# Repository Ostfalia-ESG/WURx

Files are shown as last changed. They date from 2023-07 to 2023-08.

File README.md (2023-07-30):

# Wake-up Receiver (WURx)
This project includes the main PCB design as well as the software for a semi-active Wake-up Receiver with addressing capabilities.

The WURx is the green part of the overall architecture shown in the following figure.
More details are found in the associated publications ([HotWire], [STFO]).

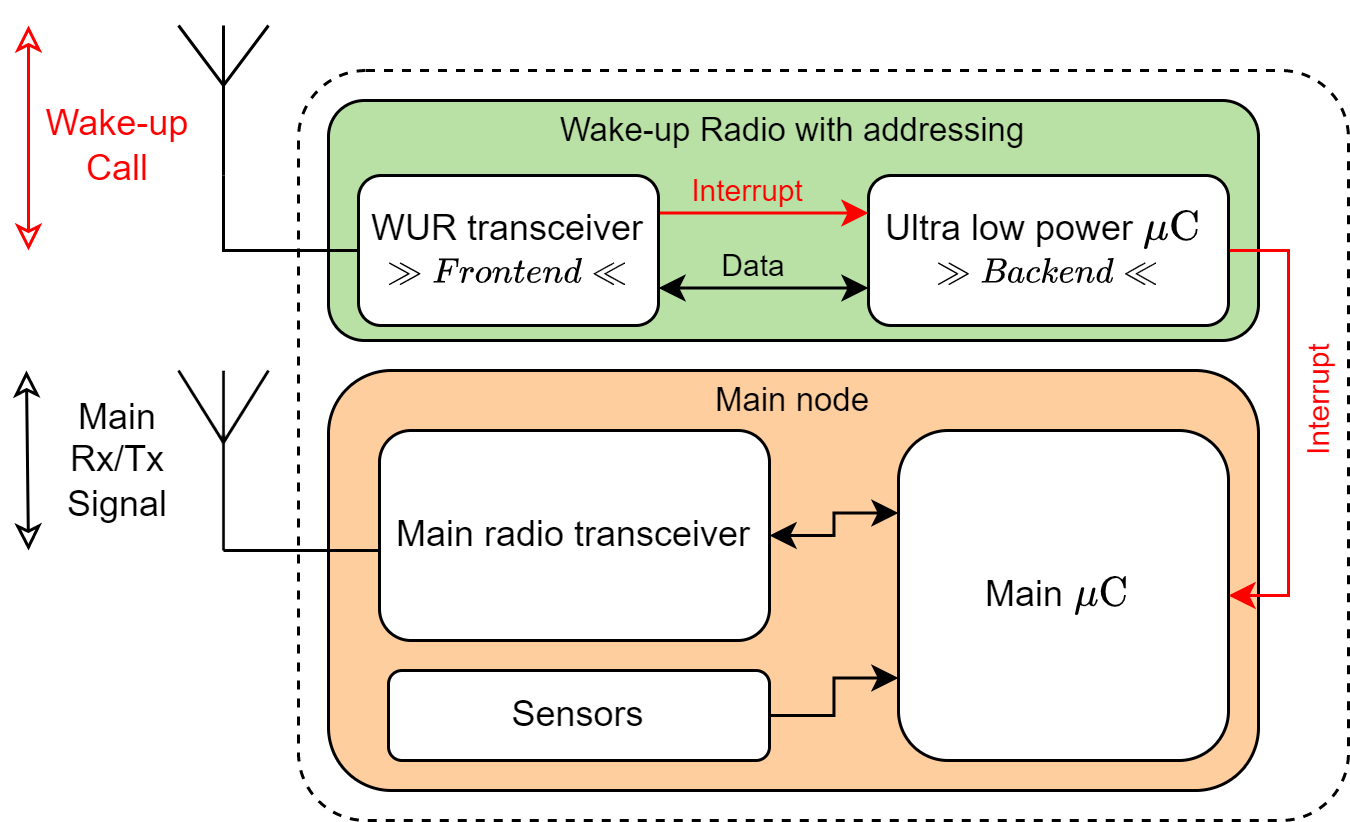
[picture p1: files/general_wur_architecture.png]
overall wur architecture


## Features
This implementation is an experimental solution for research purposes and has the following functions:

- Different comparators in the frontend are possible (TLV3691, LPV7215, TS881)
- Configurable address
- Configurable address length (0 to 32 bit)
- Configurable bitrate (100 to 25.6 kbps, with automatic clock adjustment)
- Backend supports deep-sleep and Switch (by) Transistors Fully Off (STFO) mode (see [STFO])

## Requirements
- Hardware
  - The PCBs (frontend and backend) designed in KiCad (see folder pcb/)
  - A transmitter (e.g. a Software Defined Radio like the USRP B210 with GNU Radio) is needed to send a Wake-up Call
- To program the $\mu C$ (a PIC16LF1823)
    - [MPLAB&reg; X IDE](https://www.microchip.com/en-us/tools-resources/develop/mplab-x-ide#)
    - [MPLAB&reg; XC8 C-Compiler](https://www.microchip.com/en-us/tools-resources/develop/mplab-xc-compilers/downloads-documentation#XC8)

## UART interface
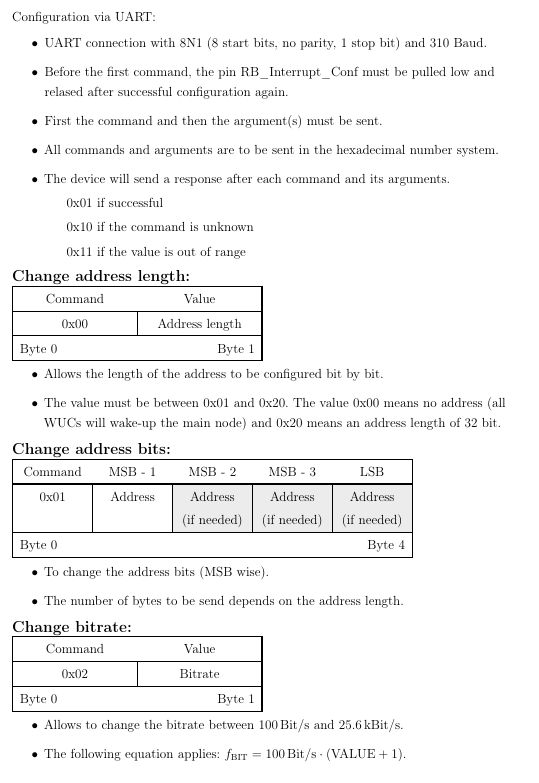
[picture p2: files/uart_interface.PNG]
UART Interface


[HotWire]: https://paper1
[STFO]: https://paper2

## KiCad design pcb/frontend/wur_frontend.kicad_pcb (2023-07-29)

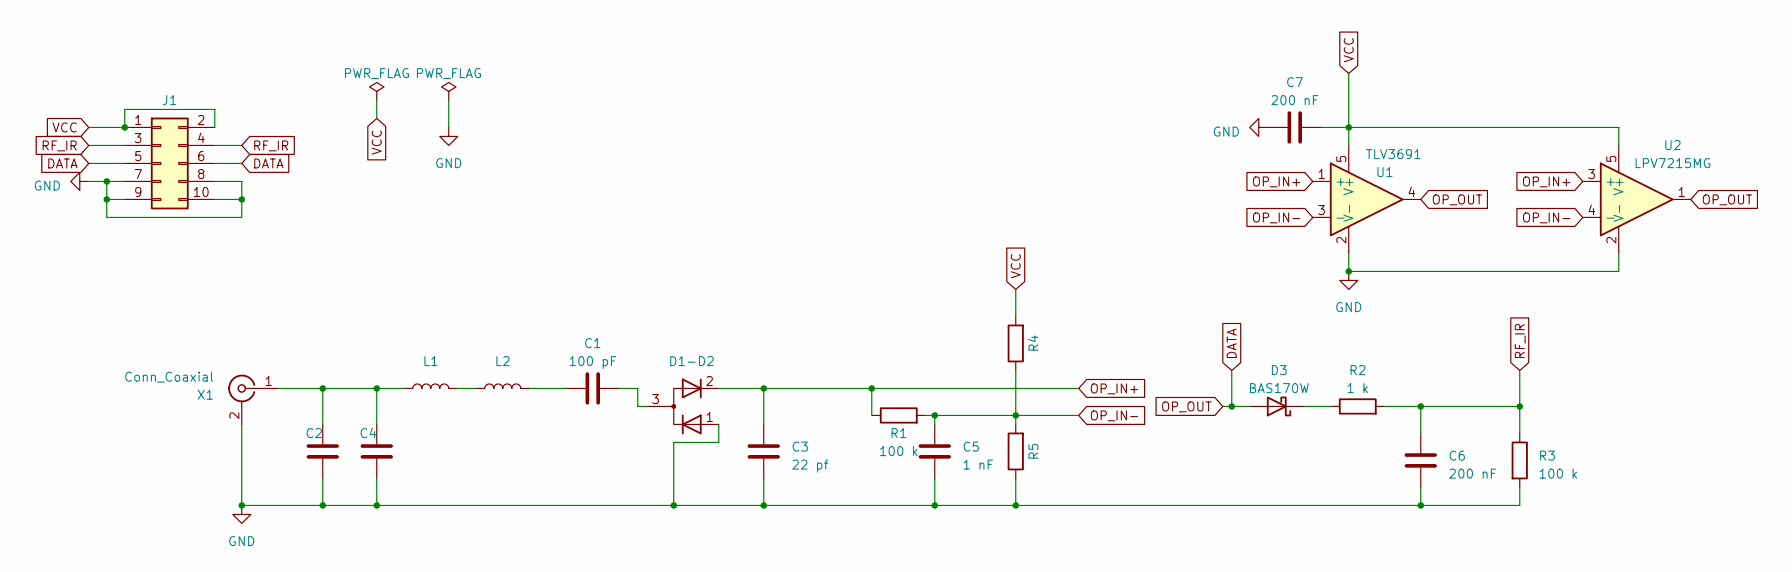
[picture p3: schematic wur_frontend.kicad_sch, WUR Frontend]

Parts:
C1: 100 pF; C_0603_1608Metric_Pad1.08x0.95mm_HandSolder
C2, C4: C_0603_1608Metric_Pad1.08x0.95mm_HandSolder
C3: 22 pf; C_0603_1608Metric_Pad1.08x0.95mm_HandSolder
C5: 1 nF; C_0603_1608Metric_Pad1.08x0.95mm_HandSolder
C6, C7: 200 nF; C_0603_1608Metric_Pad1.08x0.95mm_HandSolder
D1-D2: SOT-23
D3: BAS170W; D_SOD-323_HandSoldering
J1: Conn_02x05_Odd_Even; PinHeader_2x05_P2.54mm_Vertical
L1, L2: L; L_0603_1608Metric_Pad1.05x0.95mm_HandSolder
R1, R3: 100 k; R_0603_1608Metric_Pad0.98x0.95mm_HandSolder
R2: 1 k; R_0603_1608Metric_Pad0.98x0.95mm_HandSolder
R4, R5: R_0603_1608Metric_Pad0.98x0.95mm_HandSolder
U1: TLV3691; DCK_SC70
U2: LPV7215MG; DCK_SC70
X1: Conn_Coaxial; SMA_Amphenol_132289_EdgeMount

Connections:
DATA: D3.2 (A), J1.5, J1.6, U1.4, U2.1
GND: C2.2, C3.1, C4.2, C5.1, C6.1, C7.1, D1-D2.1 (K), J1.7, J1.8, J1.9, J1.10, R3.2, R5.1, U1.2 (V-), U2.2 (V-), X1.2 (Ext)
unnamed: C1.1, L2.2
unnamed: C1.2, D1-D2.3 (A)
unnamed: D3.1 (K), R2.1
unnamed: L1.2, L2.1
unnamed: C2.1, C4.1, L1.1, X1.1 (In)
OP_IN+: C3.2, D1-D2.2 (K), R1.1, U1.1 (+), U2.3 (+)
OP_IN-: C5.2, R1.2, R4.1, R5.2, U1.3 (-), U2.4 (-)
RF_IR: C6.2, J1.3, J1.4, R2.2, R3.1
VCC: C7.2, J1.1, J1.2, R4.2, U1.5 (V+), U2.5 (V+)

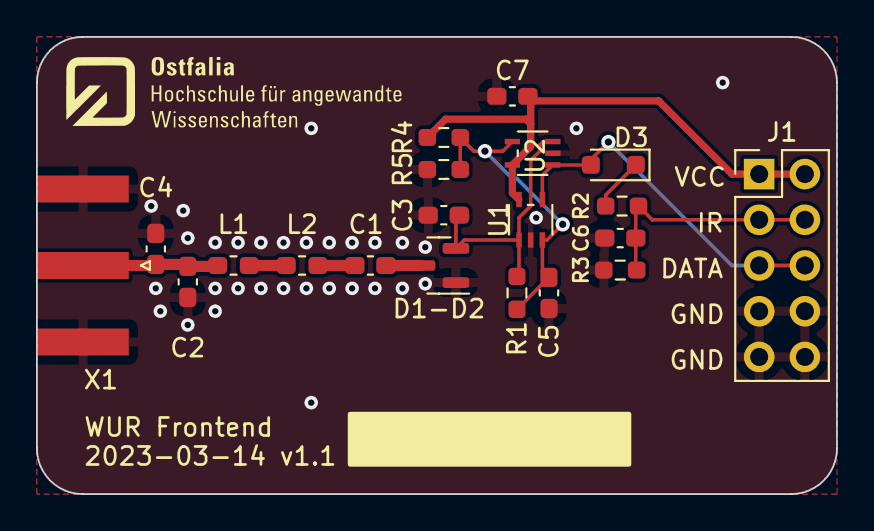
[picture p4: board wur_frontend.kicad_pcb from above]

Board: 2 copper layers, 44.5 x 25.4 mm, 20 parts (0 on the bottom side), 11 nets.

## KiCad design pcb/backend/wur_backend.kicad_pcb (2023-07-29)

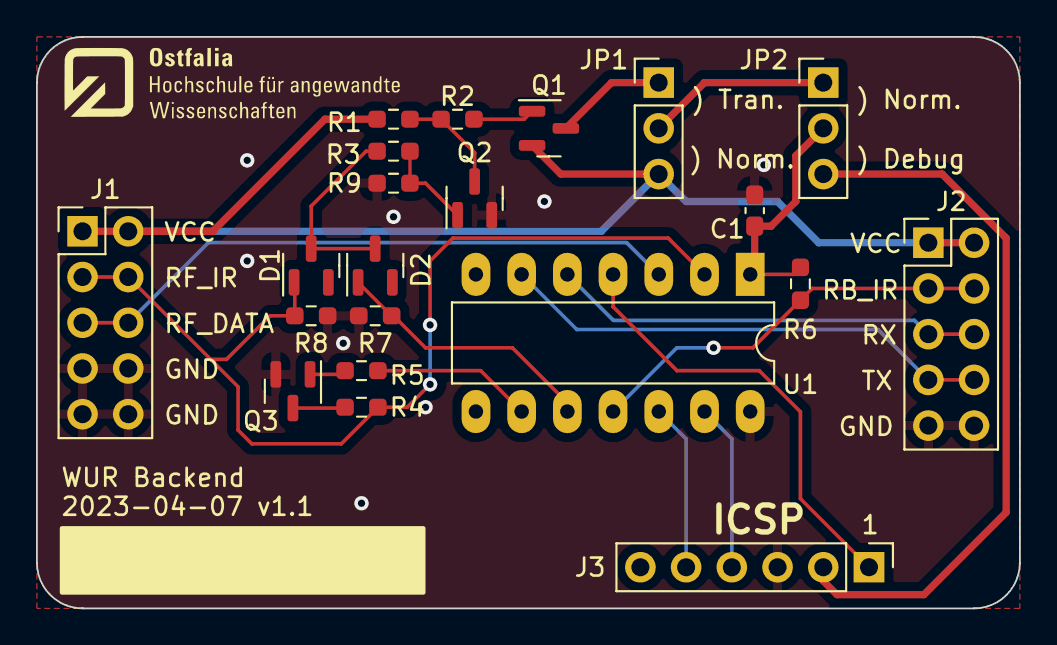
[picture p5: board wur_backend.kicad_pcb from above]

Board: 2 copper layers, 54.6 x 31.8 mm, 21 parts (0 on the bottom side), 22 nets.

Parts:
C1: 100 nF; C_0603_1608Metric_Pad1.08x0.95mm_HandSolder
D1, D2: SMMBD701LT1G; SOT-23
J1, J2: Conn_02x05_Odd_Even; PinHeader_2x05_P2.54mm_Vertical
J3: Conn_01x06; PinHeader_1x06_P2.54mm_Vertical
JP1, JP2: Jumper_3_Open; PinHeader_1x03_P2.54mm_Vertical
Q1: BC857; SOT-23
Q2, Q3: BC847; SOT-23
R1: 100 meg; R_0603_1608Metric_Pad0.98x0.95mm_HandSolder
R2: 330 k; R_0603_1608Metric_Pad0.98x0.95mm_HandSolder
R3, R9: 1 meg; R_0603_1608Metric_Pad0.98x0.95mm_HandSolder
R4: 100 Ohm; R_0603_1608Metric_Pad0.98x0.95mm_HandSolder
R5: 2.2 kOhm; R_0603_1608Metric_Pad0.98x0.95mm_HandSolder
R6: 100k; R_0603_1608Metric_Pad0.98x0.95mm_HandSolder
R7, R8: 10 meg; R_0603_1608Metric_Pad0.98x0.95mm_HandSolder
U1: DIP-14_W7.62mm_LongPads

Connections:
/RF_DISCHARGE: R5.1, U1.9 (SDI/SDA/RC1)
GND: C1.2, J1.7, J1.8, J1.9, J1.10, J2.9, J2.10, J3.3, Q2.2 (E), Q3.2 (E), R7.2, R8.1, R9.1, U1.14 (VSS)
unnamed: C1.1, JP2.2 (C), R6.1, U1.1 (VDD)
unnamed: D1.3, D2.3, R3.2
unnamed: JP1.1 (A), Q1.3 (C)
unnamed: JP1.2 (C), JP2.1 (A)
unnamed: Q1.1 (B), R2.1
unnamed: Q2.1 (B), R3.1, R9.2
unnamed: Q2.3 (C), R1.2, R2.2
unnamed: Q3.1 (B), R5.2
unnamed: Q3.3 (C), R4.1
P_ICSPCLK: J3.5, U1.12 (RA1/D-/ICSPCLK)
P_ICSPDAT: J3.4, U1.13 (RA0/D+/ICSPDAT)
P_VCC: J3.2, JP2.3 (B)
P_VPP_\MCLR: J3.1, U1.4 (RA3/T1G/~SS/~MCLR/Vpp)
RB_IR/CONF_EN: J2.3, J2.4, R6.2, U1.11 (RA2/C1OUT/T0CKI)
RF_DATA: J1.5, J1.6, U1.3 (RA4/T1G/SDO/CLKOUT/OSC2/CLKR)
RF_IR: D1.1, J1.3, J1.4, R4.2, R8.2, U1.2 (RA5/T1CKI/CLKIN/OSC1)
RF_IR_HOLD: D2.1, R7.1, U1.10 (SCK/SCL/RC0)
RX: J2.5, J2.6, U1.5 (DT/RX/RC5)
TX: J2.7, J2.8, U1.6 (CK/TX/RC4)
VCC: J1.1, J1.2, J2.1, J2.2, JP1.3 (B), Q1.2 (E), R1.1

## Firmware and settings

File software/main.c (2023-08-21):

// CONFIG1
#pragma config FOSC = INTOSC    // Oscillator Selection (INTOSC oscillator: I/O function on CLKIN pin)
#pragma config WDTE = OFF       // Watchdog Timer Enable (WDT disabled)
#pragma config PWRTE = OFF      // Power-up Timer Enable (PWRT disabled)
#pragma config MCLRE = ON       // MCLR Pin Function Select (MCLR/VPP pin function is MCLR)
#pragma config CP = OFF         // Flash Program Memory Code Protection (Program memory code protection is disabled)
#pragma config CPD = OFF        // Data Memory Code Protection (Data memory code protection is disabled)
#pragma config BOREN = OFF      // Brown-out Reset Enable (Brown-out Reset disabled)
#pragma config CLKOUTEN = OFF   // Clock Out Enable (CLKOUT function is disabled. I/O or oscillator function on the CLKOUT pin)
#pragma config IESO = OFF       // Internal/External Switchover (Internal/External Switchover mode is disabled)
#pragma config FCMEN = OFF      // Fail-Safe Clock Monitor Enable (Fail-Safe Clock Monitor is disabled)

// CONFIG2
#pragma config WRT = OFF        // Flash Memory Self-Write Protection (Write protection off)
#pragma config PLLEN = OFF      // PLL Enable (4x PLL disabled)
#pragma config STVREN = ON      // Stack Overflow/Underflow Reset Enable (Stack Overflow or Underflow will cause a Reset)
#pragma config BORV = LO        // Brown-out Reset Voltage Selection (Brown-out Reset Voltage (Vbor), low trip point selected.)
#pragma config LVP = OFF         // Low-Voltage Programming Enable (Low-voltage programming enabled)


#include <xc.h>
#include <stdio.h>
#include <stdlib.h>
#include <pic16lf1823.h>


#include "main.h"
#include "basics.h"
#include "timer.h"
#include "interrupt.h"
#include "uart.h"
#include "configuration.h"

volatile __bit ongoing_address_sampling = 0;

inline void confirm_wake_up_call(void);
inline void clear_to_sleep(void);

/*
 * Entrypoint of the application.
 * It initializes all peripheries and then switches to sleep mode 
 * until a start bit occurs.
 */
int main(void) {
#ifndef WUR_COMPILE_RELEASE
#warning No release compilation: leads to slow sampling.
#endif
    // initilize with 16 MHz to speed up the initialization routines
    OSCCONbits.IRCF = 0b1111;
    // self holding first (only important if ENABLE_TOTT is active)
    init_gpio_rf_ir_hold();
 
#ifdef SHOW_SAMPLING_POINTS
    // signals the start of the initilization routines
    init_gpio_debug_sampling();
    SET_GPIO_DEBUG_SAMPLING(1);
    NOP();
    NOP();
    SET_GPIO_DEBUG_SAMPLING(0);
#endif

    // load and init configuration (Address, Bitrate) from EEPROM 
    read_config_from_eeprom();
    init_wur_configuration(0);
    
    init_interrupts();
    init_gpio_rf_ir();
    init_gpio_rf_data();
    init_gpio_rb_ir_conf_en();
    init_gpio_rf_discharge();
    init_timer_sampling();
    init_timer_discharge();
    init_uart();
    
#ifdef SHOW_SAMPLING_POINTS 
    // signals the end of the initilization routines
    SET_GPIO_DEBUG_SAMPLING(1);
    NOP();
    NOP();
    SET_GPIO_DEBUG_SAMPLING(0);
#endif

    // user lower speed after initilization to reduce power
    OSCCONbits.IRCF = config_osccon_bits;
    
#ifndef ENABLE_TOTT
    // sleep after start and wait for interrupt on rf_ir
    ENABLE_INTERRUPT_RF_IR(1);
#else
    // When TOTT is enabled, address decoding starts directly after uC initialization
    ongoing_address_sampling = 1;
    if (wur_config.address_length != 0) {
        // wait for the sync bit
        ENABLE_INTERRUPT_RF_DATA(1); 
    } else {
        // zero address mode, confirm WUC
        confirm_wake_up_call();
        clear_to_sleep();
    }
#endif
    
    while(1) {
        if (ongoing_address_sampling == 0 && PORTAbits.RA2 == 1) {
            // if nothing is todo, go to sleep
            do_deep_sleep();
        }
        if (ongoing_address_sampling == 1) {
            // stay active during ongoing address sampling
            NOP();
        }
        // update config wehn somethin was sent via UART
        conf_loop();
    }
    return (EXIT_SUCCESS);
}

/**
 * Confirms the recept of a valid WUC for the backend.
 */
inline void confirm_wake_up_call(void) {
    SET_GPIO_RB_IR_CONF_EN();
    NOP();
    NOP();
    RESET_GPIO_RB_IR_CONF_EN();
}

/**
 * Discharges the frontend (clean state) and then goes to sleep.
 */
inline void clear_to_sleep(void) {
    // discharge frontend capacity (C6)
    while(READ_RF_DATA() == 1) {
        // wait until data pin is low
        // protects against energy waste
    }
    
    // discharge frontend for some time
    SET_GPIO_RF_DISCHARGE(1);
    START_TIMER_DISCHARGING();
}


// keeps the currently received part of the address
uint8_t address_pos = 0;
uint32_t address;

/**
 * The one interrupt service routine, that handles all events.
 */
void __interrupt() ISR_wur(void) {
    // To get the best performance, the timer 1 flag is checked first.
    if (PIR1bits.CCP1IF == 1) { // sample the current bit from data pin
        // sample current bit on data pin first!
        uint8_t data_bit = READ_RF_DATA();
        
#ifdef SHOW_SAMPLING_POINTS
        // to display sample point over pin C2
        SET_GPIO_DEBUG_SAMPLING(1);
        NOP();
        NOP();
        SET_GPIO_DEBUG_SAMPLING(0);
#endif
        
        // clear flag
        PIR1bits.CCP1IF = 0;
        
        // deocde address (MSB first)
        address_pos--;
        address <<= 1;
        address |= data_bit;
        
        if (address_pos == 0) { // all address bits sampled
            // disable sampling timer
            DISABLE_TIMER_SAMPLING();
            
            // validate the received address
            if (address == wur_config.address) {
                // correct address received
                confirm_wake_up_call();
            }
            
            address = 0;    // clear address
            clear_to_sleep();
        }
    } else if (IOCAFbits.IOCAF4 == 1) { // sync bit received
        // clear status flag
        IOCAFbits.IOCAF4 = 0;
        // disable interrupt on data pin
        ENABLE_INTERRUPT_RF_DATA(0);
        
        // start sampling center wise
        TIMER_START_VALUE(config_target_sync_timer_value);
        ENABLE_TIMER_SAMPLING();
        while(PIR1bits.CCP1IF == 0) { /** wait half a baud period **/ }
        // clear flag
        PIR1bits.CCP1IF = 0;
        
#ifdef SHOW_SAMPLING_POINTS
        // to display sync point over pin C2
        SET_GPIO_DEBUG_SAMPLING(1);
        NOP();
        SET_GPIO_DEBUG_SAMPLING(0);
#endif
        
        // set address starting position (MSB first)
        address_pos = wur_config.address_length; 
    } else if (IOCAFbits.IOCAF5 == 1) { // interrupt on rf_ir (start of a WUC)
        // clear status flag
        IOCAFbits.IOCAF5 = 0;
        
        if (wur_config.address_length != 0) { // start address decoding
            // disable interrupt
            ENABLE_INTERRUPT_RF_IR(0);
            // wait for the sync bit
            ENABLE_INTERRUPT_RF_DATA(1); 
        } else { // zero address mode, confirm WUC
            confirm_wake_up_call();
            clear_to_sleep();
        }
		ongoing_address_sampling = 1;
        
    } else if (IOCAFbits.IOCAF2 == 1) { // config mode enabled
        // clear status flag
        IOCAFbits.IOCAF2 = 0;
        /**
         * Do nothing and wait for instructions 
         * over uart, ic2 etc. in main routine.
         */
    } else if (PIR1bits.RCIF == 1) {    // handle over UART received char
        // status flag is cleard by hardware
        
        // read FIFO of the uart module
        while(PIR1bits.RCIF == 1) {
            // RCIF flag is cleared by reading RCREG register.

            if (RCSTAbits.FERR == 1) {  // invalid stop bit received?
                // ignore this character
                RCREGbits.RCREG;
                continue;
            }
            // store all characters to the internal ring buffer
            if (buffer_is_full == 1) {  // full buffer?
                // ignore this character
                RCREGbits.RCREG;
                continue;
            }
            ring_buffer[write_pointer] = (char) RCREGbits.RCREG;
            ROTATE_POINTER(&write_pointer);
            if(write_pointer == read_pointer) {
                // buffer is full
                buffer_is_full = 1;
            }
        }
    } else if (PIR1bits.TMR2IF == 1) {  // discharge completed
        // clear status flag
        PIR1bits.TMR2IF = 0;
        // stop discharging
        STOP_TIMER_DISCHARGING();
        SET_GPIO_RF_DISCHARGE(0);
     
#ifndef ENABLE_TOTT
        // go to sleep again
        ENABLE_INTERRUPT_RF_IR(1);
        ongoing_address_sampling = 0;
#else
        // PIC power off
        RELEASE_RF_IR_HOLD();
#endif
    }
    
    return;
}

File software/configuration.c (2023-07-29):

#include <stdio.h>
#include <stdlib.h>
#include <xc.h>

#include "main.h"
#include "uart.h"
#include "configuration.h"

typedef enum configuration_status_e {COMMAND, ARGUMENTS} configuration_status_et;
volatile configuration_status_et conf_status = COMMAND;

WurConfiguration wur_config;


uint8_t last_command = 0;
uint8_t address_arg_num = 0;

// Max baud rate possible due to the runtime needed by the pic to sample one bit
#define MAX_BAUD_RATE_HARD(freq) (freq / (CRITICAL_PATH_INST * 4.0 * 1.0))
// Max baud rate possible due to the runtime needed by the pic to sample one bit(with 25 % tolerance)
#define MAX_BAUD_RATE_SOFT(freq) (MAX_BAUD_RATE_HARD(freq) / TOLERANCE)
// Max baud rate argument possible for one Fosc frequency
#define MAX_BAUD_RATE_ARG(freq) (uint16_t)((MAX_BAUD_RATE_SOFT(freq) / 100.0) - 1.0)
//#define MAX_BAUD_RATE_ARG(freq) (MAX_BAUD_RATE_ARG_TEST(freq) < 0 ? (int16_t) -1 : (int16_t) MAX_BAUD_RATE_ARG_TEST(freq))

#define FREQ_31_KHZ 31000
#define FREQ_62_5_KHZ 62500
#define FREQ_125_KHZ 125000
#define FREQ_250_KHZ 250000
#define FREQ_500_KHZ 500000
#define FREQ_1_MHZ 1000000
#define FREQ_2_MHZ 2000000
#define FREQ_4_MHZ 4000000
#define FREQ_8_MHZ 8000000
#define FREQ_16_MHZ 16000000
/**
 * Timer target value:
 * value = freq / baud_rate - 1 = freq / (100 * (Arg + 1) * 4) - 1
 * To minimize ressources, the freq is precalculated to freq_value
 * freq_value = freq / 400 
 */
#define FREQ_VALUE(freq) freq / 400

uint16_t config_target_timer_value;
uint16_t config_target_sync_timer_value;
uint8_t config_osccon_bits;

// 60us discharging time (1 / (37us * 100))
#define DISCHARGING_TIME_FREQ 270

void update_time_based_params(uint16_t freq) {
    // timer1 configuration for sampling
    config_target_timer_value = (freq / (wur_config.bit_rate_arg + 1)) - 1;
    config_target_sync_timer_value = (config_target_timer_value >> 1) + SYNC_BIT_TIMER_COMPENSATION;
    
    if (config_target_sync_timer_value >= config_target_timer_value) {
        config_target_sync_timer_value = config_target_timer_value;
    }
    
    // set target compare value (with respect Fosc/4)
    CCPR1Lbits.CCPR1L = (uint8_t) config_target_timer_value;
    CCPR1Hbits.CCPR1H = (uint8_t) (config_target_timer_value >> 8);
    
    // set discharging timer period for timer 2
    PR2bits.PR2 = (uint8_t) (freq / DISCHARGING_TIME_FREQ);
}

void init_wur_configuration(uint8_t update_oscilator_clk) {
    // Set minimal oscilator frequency and params for given baudrate
    if (wur_config.bit_rate_arg <= MAX_BAUD_RATE_ARG(FREQ_31_KHZ)) {            // 31 kHz (LF))
        config_osccon_bits = 0b0000;
        update_time_based_params(FREQ_VALUE(FREQ_31_KHZ));
        // uart configuration
        // 4x multiplier
        TXSTAbits.BRGH = 1;
        BAUDCONbits.BRG16 = 1;
        SPBRGLbits.SPBRGL = (uint8_t) 24;
        SPBRGHbits.SPBRGH = (uint8_t)(24 >> 8);
    } else if (wur_config.bit_rate_arg <= MAX_BAUD_RATE_ARG(FREQ_62_5_KHZ)) {   // 62.5 kHz (MF)
        config_osccon_bits = 0b0100;
        update_time_based_params(FREQ_VALUE(FREQ_62_5_KHZ));
        // uart configuration
        // 4x multiplier
        TXSTAbits.BRGH = 1;
        BAUDCONbits.BRG16 = 1;
        SPBRGLbits.SPBRGL = (uint8_t) 49;
        SPBRGHbits.SPBRGH = (uint8_t)(49 >> 8);
    } else if (wur_config.bit_rate_arg <= MAX_BAUD_RATE_ARG(FREQ_125_KHZ)) {    // 125 kHz (MF)
        config_osccon_bits = 0b0101;
        update_time_based_params(FREQ_VALUE(FREQ_125_KHZ));
        // uart configuration
        // 4x multiplier
        TXSTAbits.BRGH = 1;
        BAUDCONbits.BRG16 = 1;
        SPBRGLbits.SPBRGL = (uint8_t) 99;
        SPBRGHbits.SPBRGH = (uint8_t)(99 >> 8);
    } else if (wur_config.bit_rate_arg <= MAX_BAUD_RATE_ARG(FREQ_250_KHZ)) {    // 250 kHz (MF)
        config_osccon_bits = 0b0110;
        update_time_based_params(FREQ_VALUE(FREQ_250_KHZ));
        // uart configuration
        // 4x multiplier
        TXSTAbits.BRGH = 1;
        BAUDCONbits.BRG16 = 1;
        SPBRGLbits.SPBRGL = (uint8_t) 200;
        SPBRGHbits.SPBRGH = (uint8_t)(200 >> 8);
    }else if (wur_config.bit_rate_arg <= MAX_BAUD_RATE_ARG(FREQ_500_KHZ)) {     // 500 kHz (MF)
        config_osccon_bits = 0b0111;
        update_time_based_params(FREQ_VALUE(FREQ_500_KHZ));
        // uart configuration
        // 4x multiplier
        TXSTAbits.BRGH = 1;
        BAUDCONbits.BRG16 = 1;
        SPBRGLbits.SPBRGL = (uint8_t) 402;
        SPBRGHbits.SPBRGH = (uint8_t)(402 >> 8);
    } else if (wur_config.bit_rate_arg <= MAX_BAUD_RATE_ARG(FREQ_1_MHZ)) {      // 1 MHz (MF)
        config_osccon_bits = 0b1011;
        update_time_based_params(FREQ_VALUE(FREQ_1_MHZ));
        // uart configuration
        // 4x multiplier
        TXSTAbits.BRGH = 1;
        BAUDCONbits.BRG16 = 1;
        SPBRGLbits.SPBRGL = (uint8_t) 805;
        SPBRGHbits.SPBRGH = (uint8_t)(805 >> 8);
    } else if (wur_config.bit_rate_arg <= MAX_BAUD_RATE_ARG(FREQ_2_MHZ)) {      // 2 MHz (MF)
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

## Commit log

2023-07-29 add pcb design
    [wur_backend.kicad_pcb, wur_backend.kicad_sch, wur_frontend.kicad_pcb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]
2023-07-29 add software
    [configuration.h]
2023-08-21 fix bug for empty address
    [main.c]

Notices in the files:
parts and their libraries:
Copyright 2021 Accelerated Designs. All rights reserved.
